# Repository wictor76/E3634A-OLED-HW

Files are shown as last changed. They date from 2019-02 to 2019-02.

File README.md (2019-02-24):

# HP/Agilent E3634A OLED display to replace old VFD

Big thanks to qu1ck!
See [Original design](https://github.com/openscopeproject/HP34401a-OLED-HW) for more information.

Original HP 34401A design was made for different OLED display. This is modified for different display pinout 
and to have USB connector pointing downwards, since I don't want to make hole to front panel display. 
Input power is also taken from front panel voltage regulator.
This board could be used also in 34401A and other PSUs using similar front panel design. 

This board was designed in KiCad 5 and uses exclusively standard KiCad libraries.

# Schematic

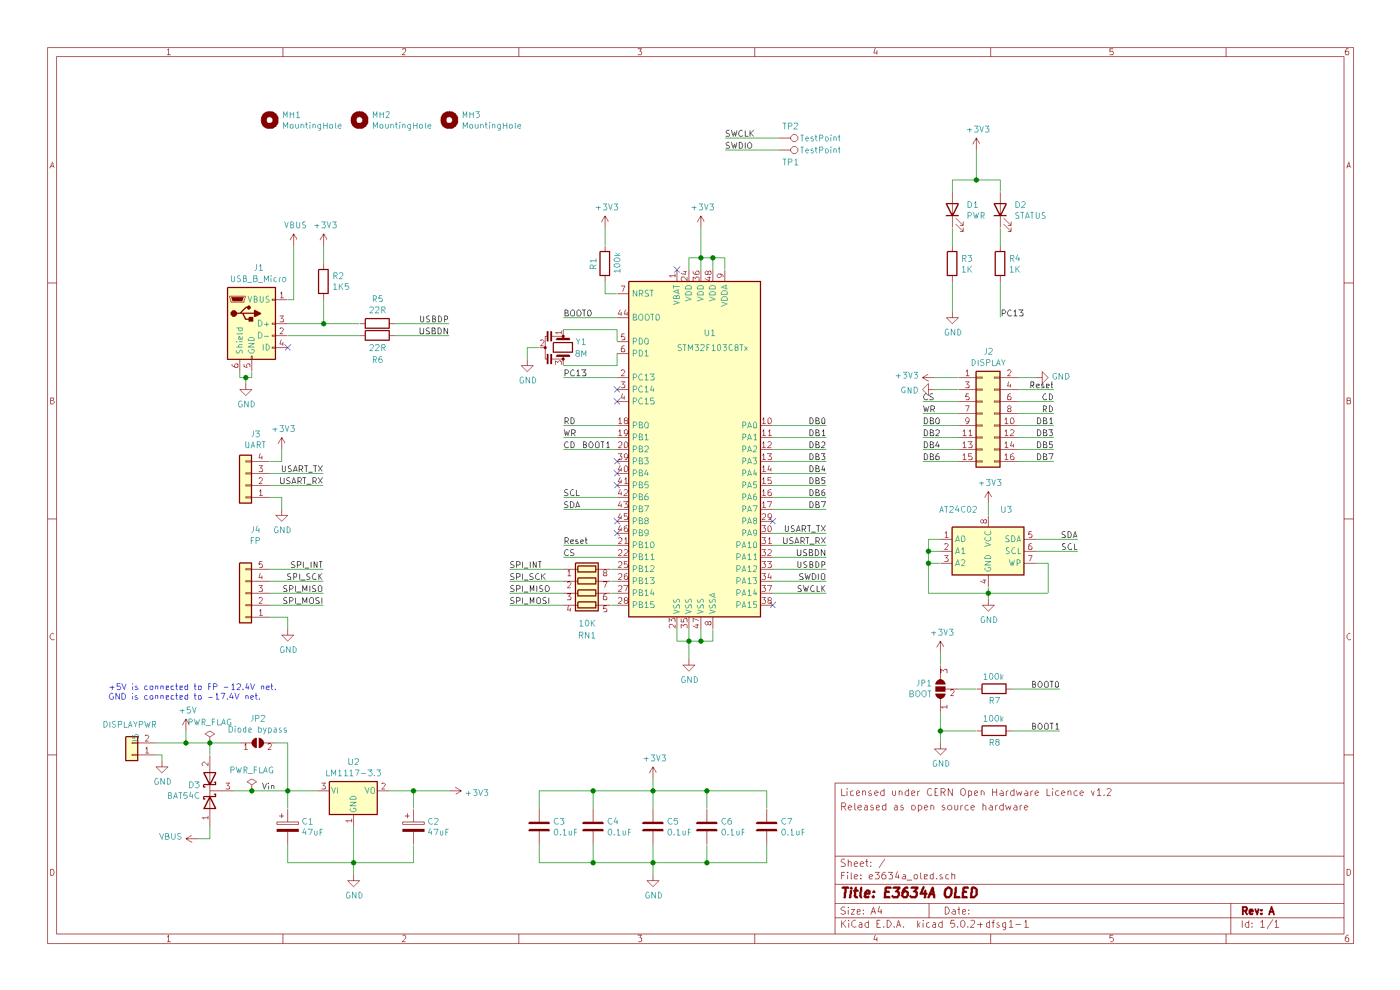
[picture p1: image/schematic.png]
schematic


# Board

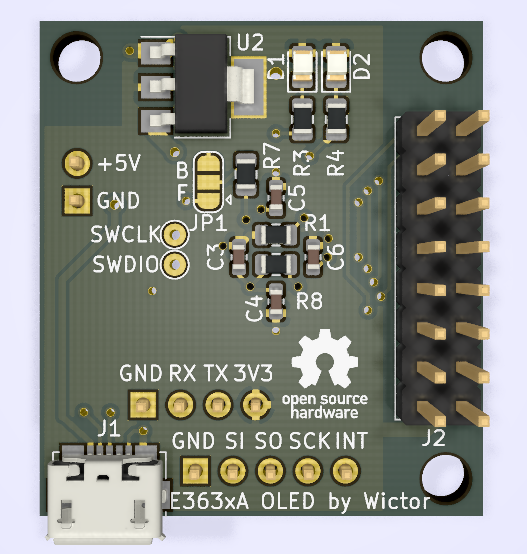
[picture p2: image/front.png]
board_front

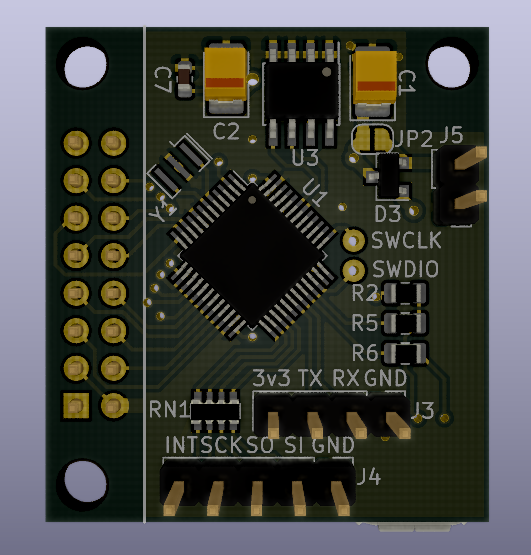
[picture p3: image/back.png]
board_back


# BOM

[Interactive BOM](https://htmlpreview.github.io/?https://github.com/wictor76/E3634A-OLED-HW/master/bom/ibom.html)

# OLED

OLED display needs to be configured for parallel data access. This display was initially configured
 for 4 wire SPI, so R18 resistor was moved to R17 to enable parallel 80XX mode.

See following image to locate resistors:
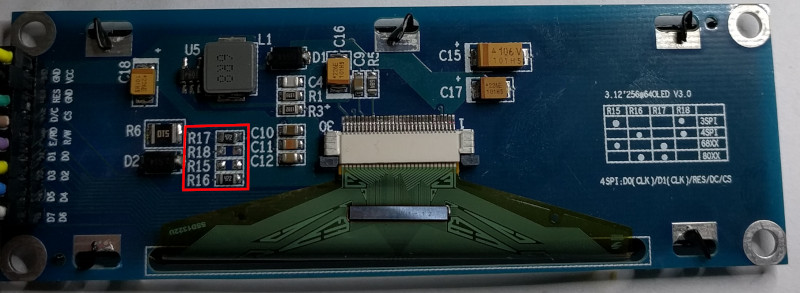
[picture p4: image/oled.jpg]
oled


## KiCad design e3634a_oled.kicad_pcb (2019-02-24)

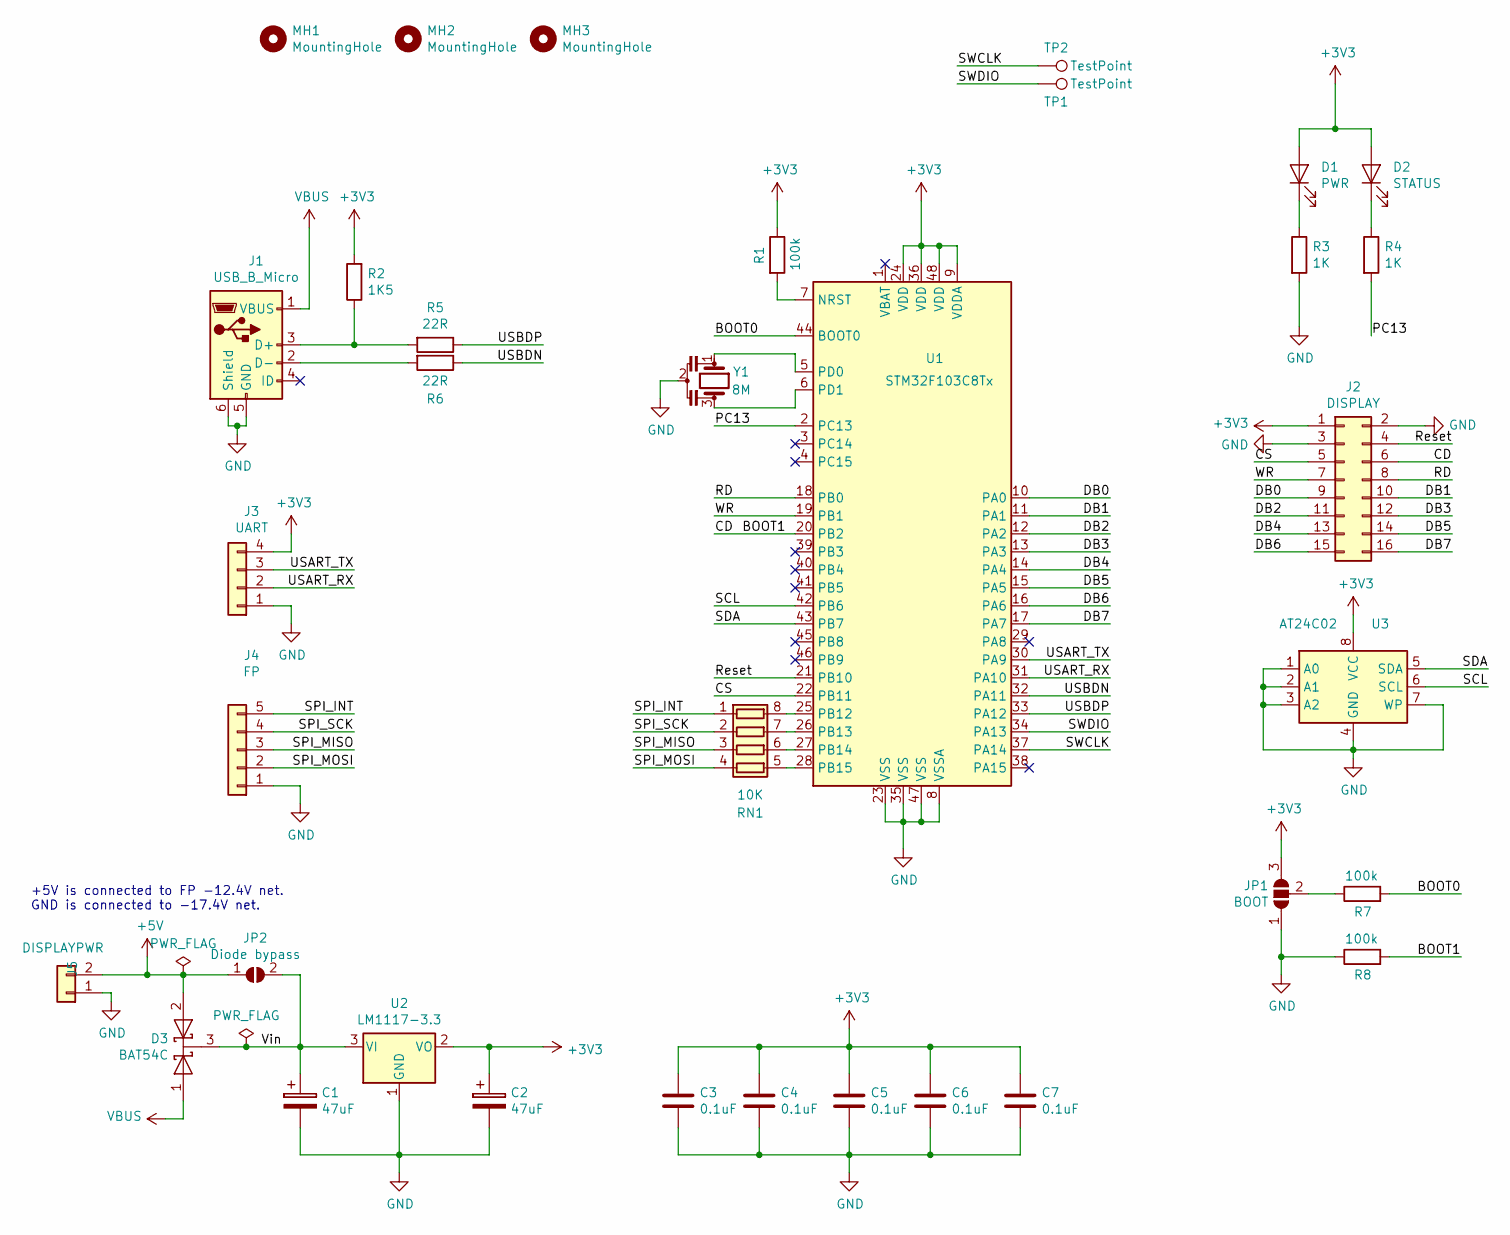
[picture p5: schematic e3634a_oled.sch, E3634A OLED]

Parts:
C1, C2: 47uF; CP_EIA-3528-21_Kemet-B_Pad1.50x2.35mm_HandSolder
C3, C4, C5, C6, C7: 0.1uF; C_0603_1608Metric
D1: PWR; LED_0805_2012Metric
D2: STATUS; LED_0805_2012Metric
D3: BAT54C; SOT-23
J1: USB_B_Micro; USB_Micro-B_Molex_47346-0001
J2: DISPLAY; PinHeader_2x08_P2.54mm_Vertical
J3: UART; PinHeader_1x04_P2.54mm_Vertical
J4: FP; PinHeader_1x05_P2.54mm_Vertical
J5: DISPLAYPWR; PinHeader_1x02_P2.54mm_Vertical
JP1: BOOT; SolderJumper-3_P1.3mm_Open_RoundedPad1.0x1.5mm
JP2: Diode bypass; SolderJumper-2_P1.3mm_Open_RoundedPad1.0x1.5mm
MH1, MH2, MH3: MountingHole; MountingHole_3.2mm_M3_ISO14580
R1, R7, R8: 100k; R_0805_2012Metric
R2: 1K5; R_0805_2012Metric
R3, R4: 1K; R_0805_2012Metric
R5, R6: 22R; R_0805_2012Metric
RN1: 10K; R_Array_Convex_4x0603
TP1, TP2: TestPoint; TestPoint_THTPad_D1.5mm_Drill0.7mm
U1: STM32F103C8Tx; LQFP-48_7x7mm_P0.5mm
U2: LM1117-3.3; SOT-223-3_TabPin2
U3: AT24C02; SOIC-8_3.9x4.9mm_P1.27mm
Y1: 8M; Resonator_SMD_muRata_CSTxExxV-3Pin_3.0x1.1mm

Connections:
+3V3: C2.1, C3.1, C4.1, C5.1, C6.1, C7.1, D1.2 (A), D2.2 (A), J2.1, J3.4, JP1.3 (B), R1.1, R2.2, U1.9 (VDDA), U1.24 (VDD), U1.36 (VDD), U1.48 (VDD), U2.2 (VO), U3.8 (VCC)
+5V: D3.2 (A), J5.2, JP2.1 (A)
/BOOT0: R7.2, U1.44 (BOOT0)
/BOOT1: J2.6, R8.2, U1.20 (PB2)
/CS: J2.5, U1.22 (PB11)
/DB0: J2.9, U1.10 (PA0)
/DB1: J2.10, U1.11 (PA1)
/DB2: J2.11, U1.12 (PA2)
/DB3: J2.12, U1.13 (PA3)
/DB4: J2.13, U1.14 (PA4)
/DB5: J2.14, U1.15 (PA5)
/DB6: J2.15, U1.16 (PA6)
/DB7: J2.16, U1.17 (PA7)
/PC13: R4.2, U1.2 (PC13)
/RD: J2.8, U1.18 (PB0)
/Reset: J2.4, U1.21 (PB10)
/SCL: U1.42 (PB6), U3.6 (SCL)
/SDA: U1.43 (PB7), U3.5 (SDA)
/SPI_INT: J4.5, RN1.1 (R1.1)
/SPI_MISO: J4.3, RN1.3 (R3.1)
/SPI_MOSI: J4.2, RN1.4 (R4.1)
/SPI_SCK: J4.4, RN1.2 (R2.1)
/SWCLK: TP2.1, U1.37 (PA14)
/SWDIO: TP1.1, U1.34 (PA13)
/USART_RX: J3.2, U1.31 (PA10)
/USART_TX: J3.3, U1.30 (PA9)
/USBDN: R6.1, U1.32 (PA11)
/USBDP: R5.1, U1.33 (PA12)
/Vin: C1.1, D3.3 (K), JP2.2 (B), U2.3 (VI)
/WR: J2.7, U1.19 (PB1)
GND: C1.2, C2.2, C3.2, C4.2, C5.2, C6.2, C7.2, J1.5 (GND), J1.6 (Shield), J2.2, J2.3, J3.1, J4.1, J5.1, JP1.1 (A), R3.2, R8.1, U1.8 (VSSA), U1.23 (VSS), U1.35 (VSS), U1.47 (VSS), U2.1 (GND), U3.1 (A0), U3.2 (A1), U3.3 (A2), U3.4 (GND), U3.7 (WP), Y1.2
unnamed: D1.1 (K), R3.1
unnamed: D2.1 (K), R4.1
unnamed: J1.2 (D-), R6.2
unnamed: J1.3 (D+), R2.1, R5.2
unnamed: JP1.2 (C), R7.1
unnamed: R1.2, U1.7 (NRST)
unnamed: RN1.5 (R4.2), U1.28 (PB15)
unnamed: RN1.6 (R3.2), U1.27 (PB14)
unnamed: RN1.7 (R2.2), U1.26 (PB13)
unnamed: RN1.8 (R1.2), U1.25 (PB12)
unnamed: U1.5 (PD0), Y1.1
unnamed: U1.6 (PD1), Y1.3
VBUS: D3.1 (A), J1.1 (VBUS)

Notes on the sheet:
+5V is connected to FP -12.4V net. GND is connected to -17.4V net.

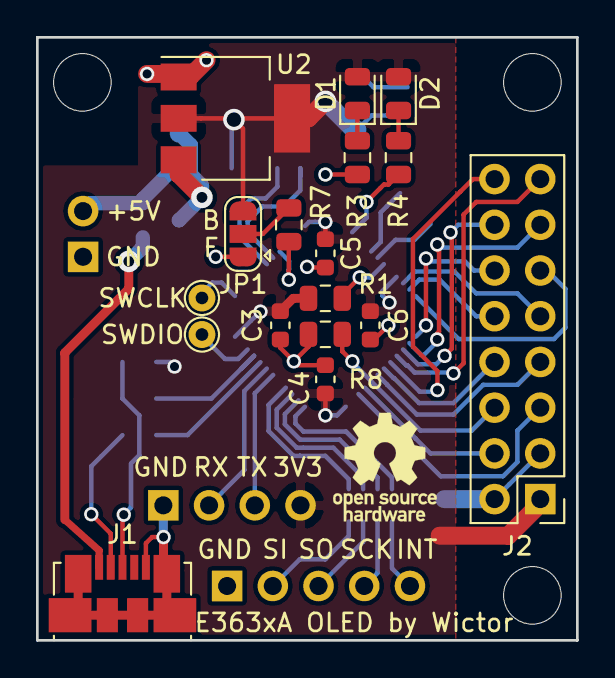
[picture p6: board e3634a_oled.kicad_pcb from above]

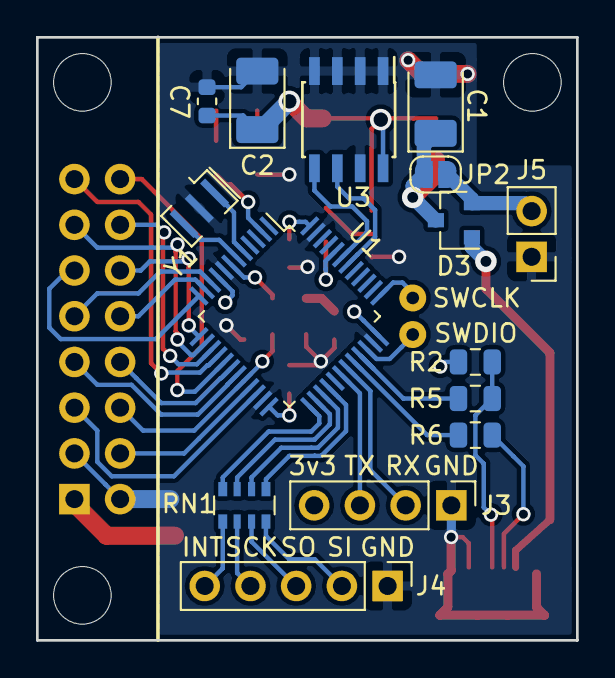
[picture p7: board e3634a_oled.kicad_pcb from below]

Board: 2 copper layers, 30.0 x 33.5 mm, 35 parts (15 on the bottom side), 44 nets.

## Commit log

2019-02-22 Modified design for different display panel
    [e3634a_oled.kicad_pcb, e3634a_oled.sch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]
2019-02-22 add schematic
2019-02-22 add pcb images
2019-02-22 add bom
2019-02-22 link to bom
2019-02-22 add gerbers for elecrow
    [e3634a_oled-B.Cu.gbl, e3634a_oled-B.Mask.gbs, e3634a_oled-B.SilkS.gbo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]
2019-02-24 add info about OLED display
    [e3634a_oled.kicad_pcb]

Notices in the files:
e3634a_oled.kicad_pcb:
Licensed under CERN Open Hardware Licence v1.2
